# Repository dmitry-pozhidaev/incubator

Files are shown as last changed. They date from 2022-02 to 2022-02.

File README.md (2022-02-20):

# incubator
Инкубатор для кибернетического выведения птенцов кур

Поделка выполнена на базе микроконтроллера STM32L011

Контроль температуры на DS1820 

Основная логика реализована посредством Дракона http://drakon-editor.sourceforge.net

Механический привод для вращения яиц сделан в Поднебесной. Ссылка на привод киберкурицы: https://aliexpress.ru/item/1005001309305247.html

pcb/eagle - принципиальная схема и печатная плата в формате Eagle

pcb/gcode - нарезка печатной платы на чпу станке. 

Используемая фреза 0.1 мм https://aliexpress.ru/item/4000966103866.html 

Станок для нарезки печатной платы https://aliexpress.ru/item/4000296585604.html

Разрешаю гражданам Великой России свободное копирование, воспроизведение и промышленное изготовление данного устройства без любых финансовых отчислений автору.
Иными представителям цивилизаций планеты Земля копирование, воспроизведение и любое промышленное или кустарное изготовление всенеприменно должно согласовываться с автором данного произведения.

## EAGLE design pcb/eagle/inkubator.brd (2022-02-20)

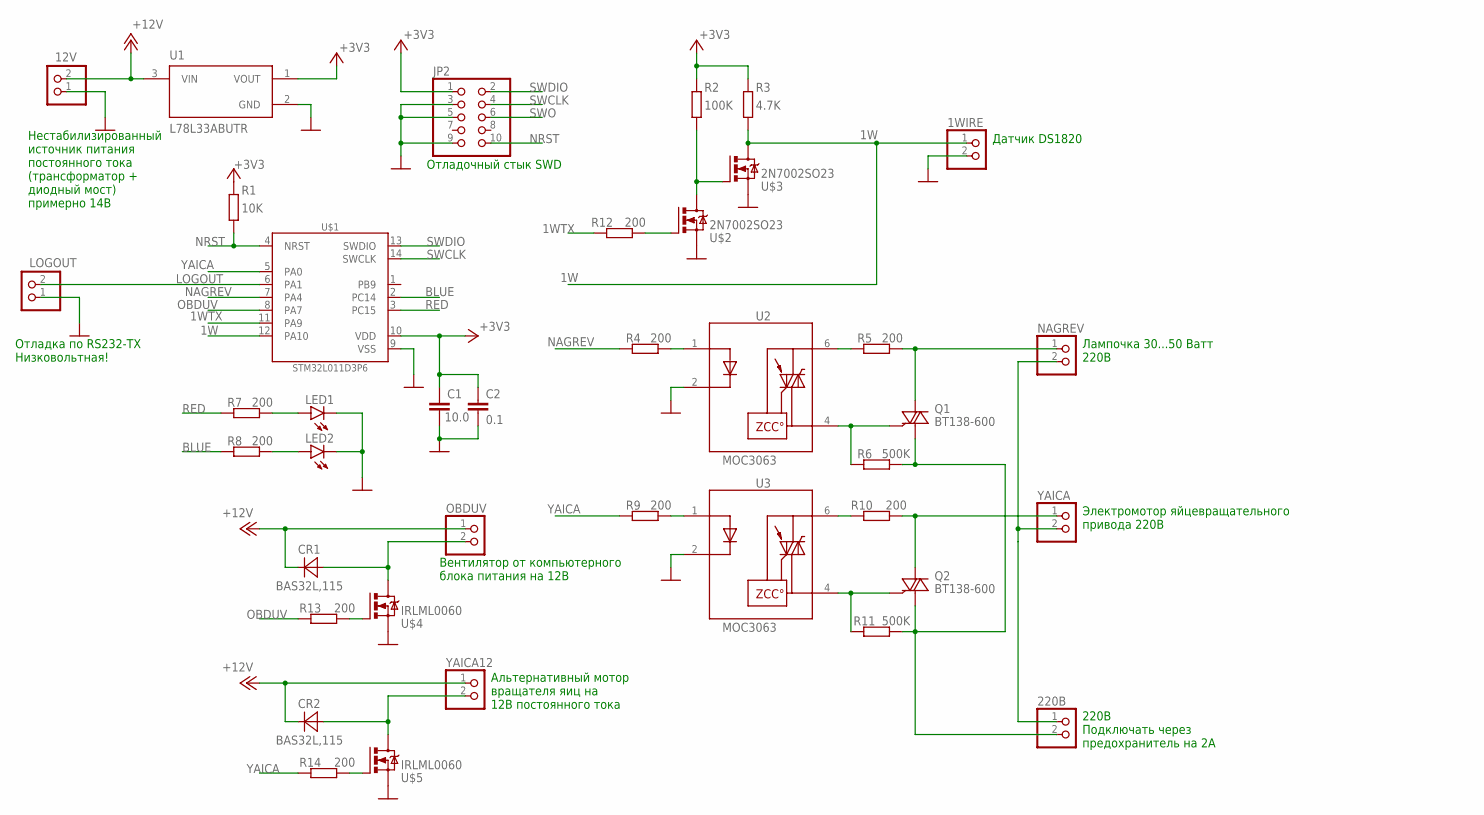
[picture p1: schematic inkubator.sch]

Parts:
1WIRE, 12V, 220В: PINHD-1X2; 1X02
C1: 10.0; C1206
C2: 0.1; C1206
CR1, CR2: BAS32L,115; SOD80C
JP2: PINHD-2X5; 2X05
LED1, LED2: LED10MM
LOGOUT: PINHD-1X2; 1X02
NAGREV: PINHD-1X2; 1X02
OBDUV: PINHD-1X2; 1X02
Q1, Q2: BT138-600; DPAK
R1: 10K; R0603
R2: 100K; R0603
R3: 4.7K; R0603
R4, R7, R8, R9, R12, R13, R14: 200; R0603
R5, R10: 200; R1206
R6, R11: 500K; R1206
U1: L78L33ABUTR; VREG_L78L12ABUTR
U2, U3: MOC3063; SOIC254P1030X460-6N
U$1: STM32L011D3P6; SOP65P640X120-14N
U$2, U$3: 2N7002SO23; SOT23
U$4, U$5: IRLML0060; SOT23
YAICA, YAICA12: PINHD-1X2; 1X02

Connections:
1W: 1WIRE.1, R3.1, U$1.12 (PA10), U$3.3 (D)
1WTX: R12.2, U$1.11 (PA9)
+3V3: C1.1, C2.1, JP2.1, R1.2, R2.2, R3.2, U1.1 (VOUT), U$1.10 (VDD)
+12V: 12V.2, CR1.1 (CATHODE), CR2.1 (CATHODE), OBDUV.1, U1.3 (VIN), YAICA12.1
BLUE: R8.2, U$1.2 (PC14)
GND: 1WIRE.2, 12V.1, C1.2, C2.2, JP2.3, JP2.5, JP2.9, LED1.K (C), LED2.K (C), LOGOUT.1, U1.2 (GND), U2.2 (C), U3.2 (C), U$1.9 (VSS), U$2.2 (S), U$3.2 (S), U$4.2 (S), U$5.2 (S)
LOGOUT: LOGOUT.2, U$1.6 (PA1)
unnamed: R2.1, U$2.3 (D), U$3.1 (G)
unnamed: R4.1, U2.1 (A)
unnamed: Q1.3 (G), R6.2, U2.4 (MT1)
unnamed: R5.2, U2.6 (MT2)
unnamed: NAGREV.1, Q1.2 (A2), R5.1
unnamed: 220В.1, NAGREV.2, YAICA.2
unnamed: R9.1, U3.1 (A)
unnamed: Q2.3 (G), R11.2, U3.4 (MT1)
unnamed: LED1.A, R7.1
unnamed: LED2.A, R8.1
unnamed: R10.2, U3.6 (MT2)
unnamed: Q2.2 (A2), R10.1, YAICA.1
unnamed: 220В.2, Q1.1 (A1), Q2.1 (A1), R6.1, R11.1
unnamed: R12.1, U$2.1 (G)
unnamed: R13.1, U$4.1 (G)
unnamed: CR1.2 (ANODE), OBDUV.2, U$4.3 (D)
unnamed: R14.1, U$5.1 (G)
unnamed: CR2.2 (ANODE), U$5.3 (D), YAICA12.2
NAGREV: R4.2, U$1.7 (PA4)
NRST: JP2.10, R1.1, U$1.4 (NRST)
OBDUV: R13.2, U$1.8 (PA7)
RED: R7.2, U$1.3 (PC15)
SWCLK: JP2.4, U$1.14 (SWCLK)
SWDIO: JP2.2, U$1.13 (SWDIO)
SWO: JP2.6
YAICA: R9.2, R14.2, U$1.5 (PA0)

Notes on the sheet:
Лампочка 30...50 Ватт 220В
Электромотор яйцевращательного привода 220В
Датчик DS1820
Вентилятор от компьютерного блока питания на 12В
Отладка по RS232-TX Низковольтная!
Нестабилизированный источник питания постоянного тока (трансформатор + диодный мост) примерно 14В
Отладочный стык SWD
220В Подключать через предохранитель на 2А
Альтернативный мотор вращателя яиц на 12В постоянного тока

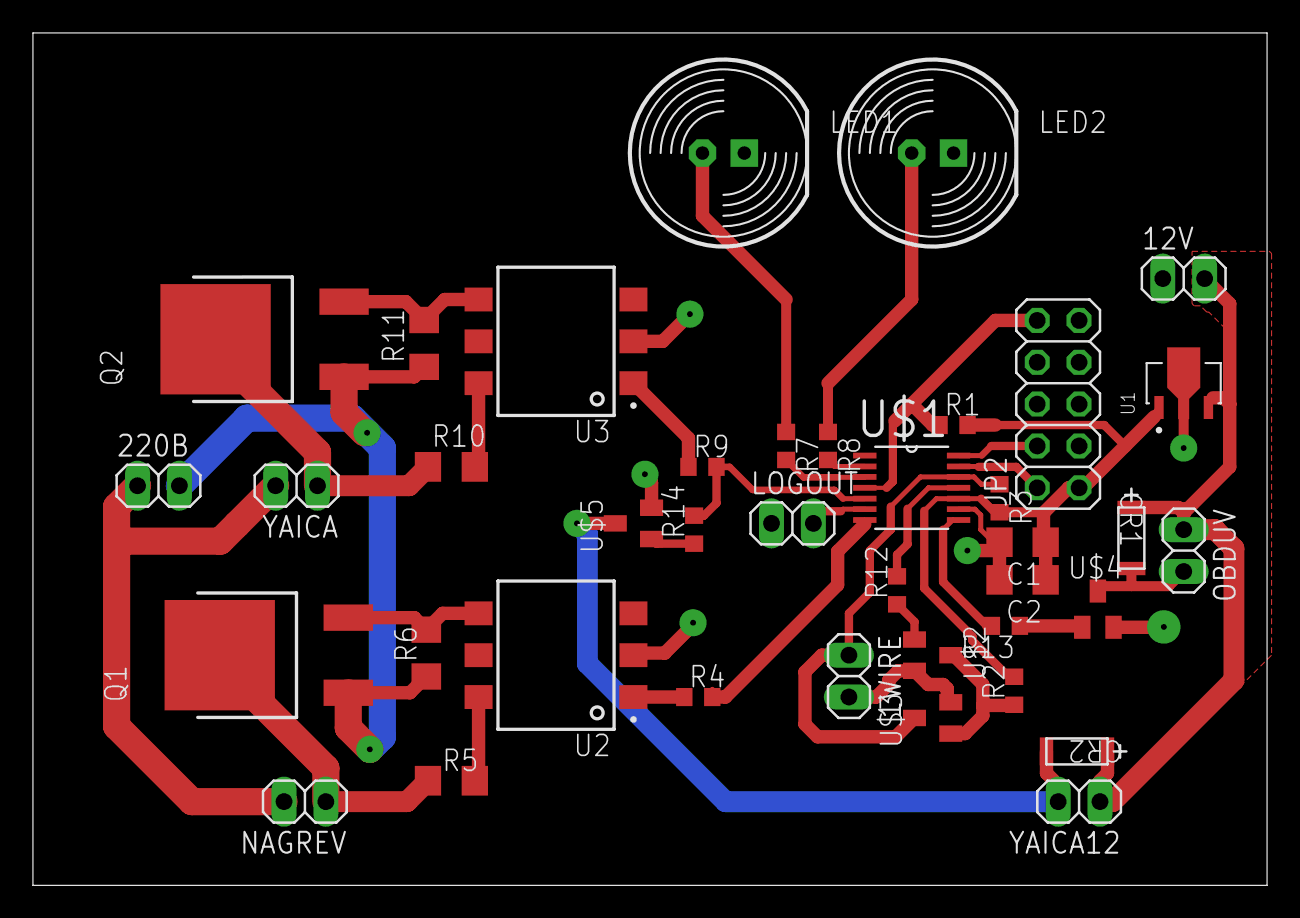
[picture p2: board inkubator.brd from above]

Board: 2 copper layers, 74.9 x 51.7 mm, 39 parts (0 on the bottom side), 32 nets.

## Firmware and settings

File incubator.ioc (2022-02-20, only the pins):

Mcu.UserName=STM32L011D3Px
PA1.Signal=LPUART1_TX
PA10.Signal=USART2_RX
PA13.Signal=SYS_SWDIO
PA14.Signal=SYS_SWCLK
PA4.GPIO_Label=OBDUV
PA4.Signal=GPIO_Output
PA7.GPIO_Label=NAGREV
PA7.Signal=GPIO_Output
PA9.Signal=USART2_TX
PC14-OSC32_IN.GPIO_Label=BLUE
PC14-OSC32_IN.Signal=GPIO_Output
PC15-OSC32_OUT.GPIO_Label=RED
PC15-OSC32_OUT.Signal=GPIO_Output

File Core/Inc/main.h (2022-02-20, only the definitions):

#define OBDUV_Pin GPIO_PIN_4
#define OBDUV_GPIO_Port GPIOA
#define NAGREV_Pin GPIO_PIN_7
#define NAGREV_GPIO_Port GPIOA

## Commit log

2022-02-20 Добавлена схема и недоделанная плата
    [inkubator.brd, inkubator.sch]
2022-02-20 пустой проект Дракона добавлен
2022-02-20 Первая версия печатной платы
    [inkubator.brd]
2022-02-20 Рефакторинг печатной платы
2022-02-20 Рефакторинг принципиальной схемы и печатной платы
    [inkubator.brd, inkubator.sch]
2022-02-20 Добавлен узел управления 12-и вольтовым мотором привода яйцекрутилки, для случая если мотор DC 12V
    [inkubator.brd, inkubator.sch]
2022-02-20 Рефакторинг сетевой разводки
    [inkubator.brd]

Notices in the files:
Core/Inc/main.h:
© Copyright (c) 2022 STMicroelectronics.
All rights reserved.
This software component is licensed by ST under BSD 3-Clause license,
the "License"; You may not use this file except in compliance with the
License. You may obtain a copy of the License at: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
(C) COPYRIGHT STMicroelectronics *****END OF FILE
